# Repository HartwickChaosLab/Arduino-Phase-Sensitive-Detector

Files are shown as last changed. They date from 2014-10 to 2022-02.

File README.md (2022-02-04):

Arduino-Phase-Sensitive-Detector
================================

Arduino and Processing Code GPLv3
Talk CC-BY-SA 4.0

To use this software:
  Download: PSDArduino.ino from the PSDArduino folder and load onto your Arduino
  Download: PSDDrawProcessing.pde from the PSDDrawProcessing folder onto your computer
  
With your arduino running PSDArduino and connected to your computer, run PSDDrawProcessing.pde in the Processing environment

To use the PSD follow PSD_schematic_phase_schem.pdf found in the PSD-Talk folder.

To test the PSD with a phase-shifting circuit follow PhaseShift.pdf in the PSD-Talk folder. The input of the ciruit is attached to the Arduino port supplying the reference signal, the output goes to the Arduino input grabbing the signal. The resistors in the inverting branch should be roughly equal to provide 1V/V gain. I used 10k resistors. The pot in the non-inverting branch was 10k and the capacitor was chosen to create a 90 degree phase shift at the reference frequency, which occurs at 1/(2*pi*R*C). The reference frequency is determined by the Arduino code by fr=(TCNT2 rate)/(OCR2A * wavetable length)

20220202 Forrest Erickson
For the Processing sketch I have modified to show all four traces 

I have added sqaure wave output on pins 7 and 8.
I have moved the sine and cosine table into PROGMEM so 
Sketch uses 4832 bytes (14%) of program storage space. Maximum is 32256 bytes.
Global variables use 715 bytes (34%) of dynamic memory, leaving 1333 bytes for local variables. Maximum is 2048 bytes.

I have stopped the overlfow on the mixer mathematics and scaled the output to -2.5 to 2.5 around Vcc/2.

Here is the Arduino serial plotter output when I input the sqaure wave into the analog input (which I moved to A2 for my hardware) for both the pins 8 and 7 (in phage and 90 degree shift)

**ScreenCaptureIQMPV2.0.0.gif**
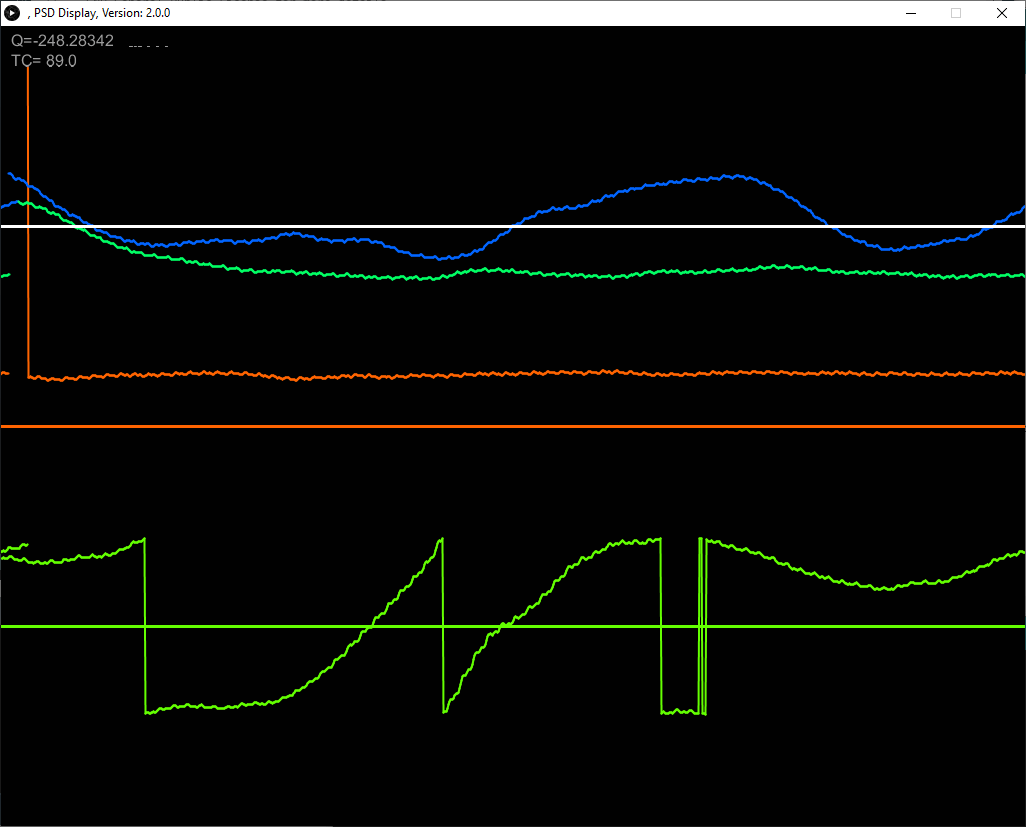
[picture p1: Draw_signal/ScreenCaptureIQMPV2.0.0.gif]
  

**SerialPlotPin8I**  
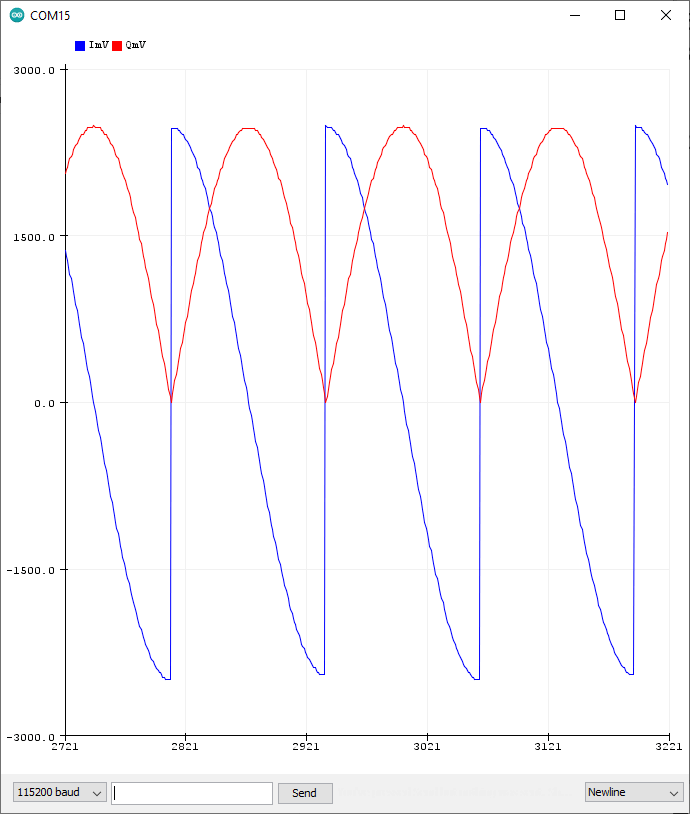
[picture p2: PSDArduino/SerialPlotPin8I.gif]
  
 
**SerialPlotPin7Q**  
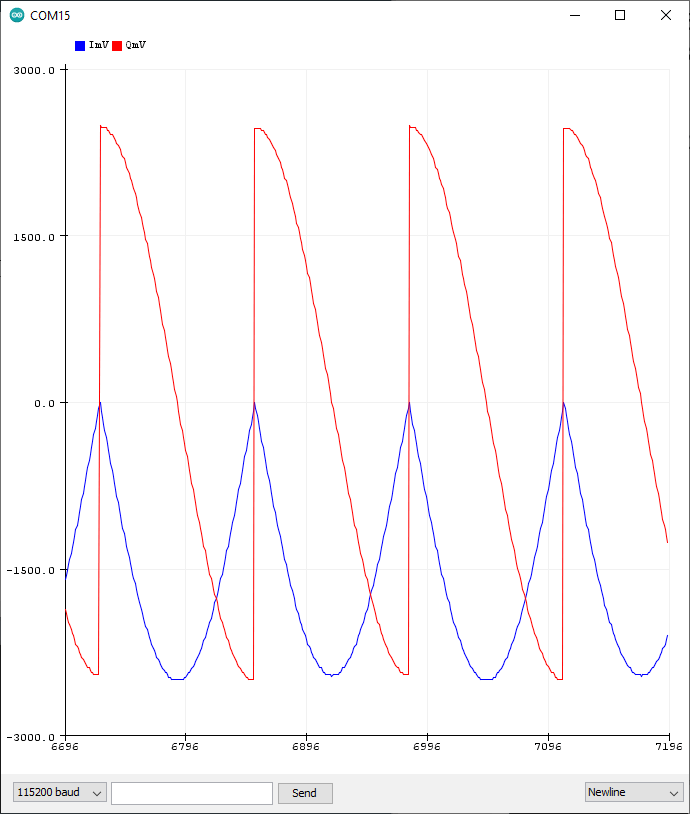
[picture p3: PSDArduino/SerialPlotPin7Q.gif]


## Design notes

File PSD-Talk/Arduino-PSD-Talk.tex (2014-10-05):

% !TEX TS-program = pdflatex
% !TEX encoding = UTF-8 Unicode

% This file is a template using the "beamer" package to create slides for a talk or presentation
% - Talk at a conference/colloquium.
% - Talk length is about 20min.
% - Style is ornate.

% MODIFIED by Jonathan Kew, 2008-07-06
% The header comments and encoding in this file were modified for inclusion with TeXworks.
% The content is otherwise unchanged from the original distributed with the beamer package.

\documentclass{beamer}
\usepackage{hyperref}

%This file is released under (CC BY-SA 4.0) license. See the following website for details http://creativecommons.org/licenses/by-sa/4.0/legalcode

\mode<presentation>
{
  \usetheme{Warsaw}
  % or ...

  %\setbeamercovered{transparent}
  % or whatever (possibly just delete it)
}

\usepackage[english]{babel}
% or whatever

\usepackage[utf8]{inputenc}
% or whatever
\usepackage[graphics]{}
\usepackage[amsmath]{}
\usepackage{times}
\usepackage[T1]{fontenc}
% Or whatever. Note that the encoding and the font should match. If T1
% does not look nice, try deleting the line with the fontenc.

\title[PSD with Arduino CC-BY-SA.4.0] % (optional, use only with long paper titles)
{The trials and tribulations of building a phase-sensitive detector with an Arduino microcontroller}

\author[K.\ D.\ Schultz] % (optional, use only with lots of authors)
{K.~D.~Schultz}
% - Give the names in the same order as the appear in the paper.
% - Use the \inst{?} command only if the authors have different
%   affiliation.

\institute[Hartwick College] % (optional, but mostly needed)
{
 
  Department of Physics\\
  Hartwick College
}
% - Use the \inst command only if there are several affiliations.
% - Keep it simple, no one is interested in your street address.

\date[MAS-APS] % (optional, should be abbreviation of conference name)
{MAS-APS, 2014}
% - Either use conference name or its abbreviation.
% - Not really informative to the audience, more for people (including
%   yourself) who are reading the slides online

% This is only inserted into the PDF information catalog. Can be left
% out. 

% If you have a file called "university-logo-filename.xxx", where xxx
% is a graphic format that can be processed by latex or pdflatex,
% resp., then you can add a logo as follows:

 \pgfdeclareimage[height=0.5cm]{university-logo}{HartwickLogo}
 \logo{\pgfuseimage{university-logo}}

% Delete this, if you do not want the table of contents to pop up at
% the beginning of each subsection:
%\AtBeginSubsection[]
%{
%  \begin{frame}<beamer>{Outline}
%    \tableofcontents[currentsection,currentsubsection]
%  \end{frame}
%}

% If you wish to uncover everything in a step-wise fashion, uncomment
% the following command: 

%\beamerdefaultoverlayspecification{<+->}

\begin{document}

\begin{frame}
  \titlepage
\end{frame}

%\begin{frame}{Outline}
%  \tableofcontents
%  % You might wish to add the option [pausesections]
%\end{frame}

% Structuring a talk is a difficult task and the following structure
% may not be suitable. Here are some rules that apply for this
% solution: 

% - Exactly two or three sections (other than the summary).
% - At *most* three subsections per section.
% - Talk about 30s to 2min per frame. So there should be between about
%   15 and 30 frames, all told.

% - A conference audience is likely to know very little of what you
%   are going to talk about. So *simplify*!
% - In a 20min talk, getting the main ideas across is hard
%   enough. Leave out details, even if it means being less precise than
%   you think necessary.
% - If you omit details that are vital to the proof/implementation,
%   just say so once. Everybody will be happy with that.

\section {Introduction}

\subsection{Original Goals}

\begin{frame}
\frametitle{Original Goals}

\begin{itemize}%[<+-|alert@+>]
\item {Use Arduino as a tool for teaching about phase-sensitive detection.}
\item{To do so with only the Arduino, a computer for display purposes, and passive external components (resistors and capacitors)}

\end{itemize}
\end{frame}

\subsection{Motivation}
\begin{frame}
\frametitle{Why PSD?}
\begin{itemize}%[<+-| alert@+>]
\item{Phase Sensitive Detection (PSD) is the basis of many techniques in physics and engineering}
\begin{itemize}
\item{Homodyne detection}
\item{Interferometry}
\item{Lock-in amplifiers}

\end{itemize}

\item {Black boxes are useful for application work, but not so much for pedagogical purposes}
\item {Software PSD allows students to peek into the black box.}

\end{itemize}

\end{frame}
\begin{frame}
\frametitle{Why Arduino?}
\begin{columns}[t]
\column[c]{0.6\textwidth}
\begin{itemize}
\item{Cheap}
\item {Popular}
\begin{itemize}
\item {Lots of support}
\end{itemize}
\item {Simple programming environment}
\begin{itemize}
\item {Perhaps too simple, IDE has very poor debugging tools.}
\end{itemize}
\item{Works well with Processing, which is a free and powerful language for visualization}
\item{Both Arduino and Processing are platform agnostic: Windows, Linux, OS X, Raspberry Pi...}
\end{itemize}
\column[c]{0.4\textwidth}
\begin{figure}
\hspace*{-.75cm}\\
\tiny {Arduino picture from Sparkfun CC-BY-2.0}
\end{figure}
\end{columns}
\end{frame}

\subsection{Background Material}
\begin{frame}
\frametitle{PSD Basics}

\begin{columns}[t]
	\column[c]{4.5cm}
	    
	\column[c]{6.6cm}
\small	
	\begin{block}{Mathematics of PSD}
	
	\begin{align*}
	V_{mix}&=V_s V_r \left [ ( \cos\left(\omega_s-\omega_r\right)t-(\phi_s-\phi_r)\right]\\
	V_o&=A \frac{V_s V_r}{2} \left[ \cos(\phi_s-\phi_r)\right]
	\end{align*}
	
	\end{block}

\begin{block}{Restrictions}
\begin{itemize}
\item $\omega_r=\omega_s$
\item\alert{ $V_s$ and $V_r$ have no DC offset}
\end{itemize}
\end{block}

\end{columns}
\end{frame}

\section{Is This Even Possible?}

%\begin{frame}
%\frametitle{What do we need? Can we do it?}
%\begin{columns}
%\column[T]{.5\textwidth}
%\begin{block}{Needed features}
%\begin{enumerate}
%
%\item {Generate reference signal.}
%\item {Adjustable phase to maximize signal.}
%\item {Get signal into Arduino}
%\item {Mix signal and reference and filter the results}
%\item {Display results}
%\end{enumerate}
%\end{block}
%\pause
%\column[T]{.5\textwidth}
%\begin{block}{Issues}
%\begin{enumerate}%[<+->]
%\item{Arduino has no analog out}
%\item{Shifting phase is difficult to do internally}
%\item{Positive voltages only}
%\item{Limited variable memory on Arduino}
%\item{Need to use serial over USB to Processing}
%\end{enumerate}
%\end{block}
%\end{columns}
%\end{frame}

\begin{frame}
\frametitle{Flowchart}

\end{frame}

\subsection{Making it Work}
\begin{frame}
\frametitle{Phase Manipulation}
\begin{columns}[t]
\column[c]{0.3\textwidth}


\column[c]{0.7\textwidth}

\begin{itemize}
\item {Need to be able to shift phase to maximize signal}
\item {All-pass phase shifters work, but require a bit more hardware external to Ardunio}
\item {Software solutions difficult to implement}
\item {Use two phase detection.}
	\begin{itemize}
	\item $V_I=V_s\times \cos(\theta), V_Q=V_s\times\sin(\theta)$
	\item $R=\sqrt{V_I^2+V_Q^2}$
	\item $\phi=\tan^{-1}(V_Q/V_I)$
	\end{itemize}
\end{itemize}

\end{columns}
\end{frame}

\begin{frame}
\frametitle{Creating a Reference Signal}
\begin{columns}[t]
	\column[c]{6cm}
	\begin{figure}
	    \\
	    \tiny{ Picture adapted from J. Thompson, MAKE vol. 35}
	    \end{figure}
	    
	\column[c]{5cm}

	\begin{block}{Timers and Interrupts Part I}
	\begin{itemize}
	\item {The ratio of PWM on to off determines an average ``DC'' signal}
	\item{When register TCNT1 reaches OCR1A PWM goes low}
	\item {When TCNT1 overflows PWM goes high again}
	\end{itemize}
	
	\end{block}
\end{columns}
\end{frame}

\begin{frame}
\frametitle{Creating a Reference Signal}
\begin{columns}[T]
	\column[T]{.4\textwidth}
	\vspace{.5cm}
	   \begin{figure}
	    \\
	    \tiny {Picture adapted from J. Thompson, MAKE vol. 35}
	    \end{figure}
	    \vspace{.3cm}
	    \begin{block}
	    $f_{ref}=\frac{\text{TCNT2 rate}}{\text{OCR2A value}\times\text{wavetable length}}$
	    \end{block}
	\column[T]{.5\textwidth}

	\begin{block}{Timers and Interrupts Part II}
	\begin{itemize}
	\item {Need fast timer2 and regular timer1, which outputs PWM}
	\item{When timer2 reaches OCR2A:}
	\begin{itemize}
        \item {Update OCR1A from wavetable}
        \item{ read signal at AnalogIn}
	\end{itemize}
	\item{When timer1 counts up to OCR1A, PWM goes low}
	\item {When timer1 overflows PWM goes high again}
	
	\end{itemize}
	
	\end{block}
\end{columns}
\end{frame}

\begin{frame}
\frametitle{Signal Input}
\begin{center}
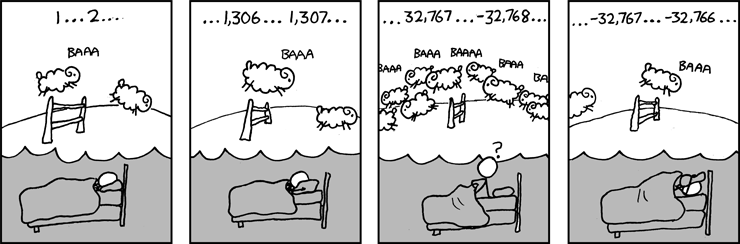
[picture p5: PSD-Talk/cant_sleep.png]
\hspace*{-.45cm}
\end{center}
\end{frame}
\begin{frame}
\frametitle{Signal Input}
\begin{itemize}
	\item {Arduino can only have positive voltages at its inputs or outputs}
		\begin{itemize}
			\item {Integer overflow when mixing}
			\item {Necessary DC offsets makes phase indefinite}
		\end{itemize}
	\item {Need to run ADC as fast as we can so as to to interfere with reference generation.}

		\begin{itemize}
			\item{Setting pre-scalars and registers can get sampling rates of 50k samples/sec. Not bad for  a 30 board!}
			\item{ADC has 10 bit resolution with adjustable $V_{ref}$, so resolution on the order of a millivolt is possible}
		\end{itemize}
\end{itemize}

\end{frame}

\begin{frame}
\frametitle{Display}
\begin{columns}
\column{.5\textwidth}
\begin{figure}
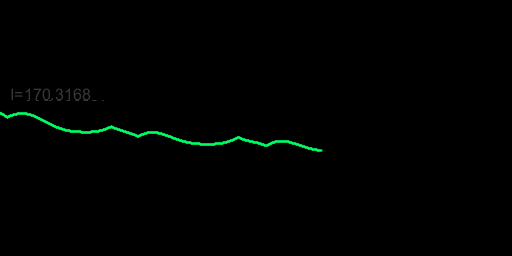
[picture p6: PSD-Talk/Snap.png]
\\
In-phase channel as phase is changed
\end{figure}
\column{.5\textwidth}

\end{columns}
\end{frame}

\section{Conclusions}
\begin{frame}
\begin{columns}
\column[T]{.5\textwidth}
\begin{block}{What we accomplished}
\begin{itemize}
\item {Built and tested a working two-channel phase-sensitive detector}
\item {Learned techniques that can be used for other micro-processor based instruments}
\item {Published on github under GPL v3 license}
\end{itemize}
\end{block}

\column[T]{.5\textwidth}
\begin{block}{Still to do}
\begin{itemize}
\item {Characterize detector (noise, internal phase shift, etc...)}
\item {Clean up display}
\item {Explore other memory options on Arduino}
\item {Use in an application}
\end{itemize}
\end{block}
\end{columns}
\end{frame}
% All of the following is optional and typically not needed. 
\appendix
\section<presentation>*{\appendixname}
\subsection<presentation>*{For Further Reading}

\begin{frame}[allowframebreaks]
  \frametitle<presentation>{For Further Reading}
    
  \begin{thebibliography}{10}
    
%  \beamertemplatebookbibitems
%  % Start with overview books.
%
%  \bibitem{Author1990}
%    A.~Author.
%    \newblock {\em Handbook of Everything}.
%    \newblock Some Press, 1990.

  \beamertemplateinternetbibitems
  % Followed by interesting articles. Keep the list short. 
\small{
  \bibitem{github2014}
    The programs!
    \newblock \url{https://github.com/HartwickChaosLab/Arduino-Phase-Sensitive-Detector}
   
   \bibitem{arduino}
   Arduino
   \newblock \url{http://www.arduino.cc}
   
   \bibitem{Processing}
   Processing
   \newblock \url{http://processing.org}
   
   \bibitem{measuring stuff}
   Moding the Arduino ADC
   \newblock \url{https://sites.google.com/site/measuringstuff/the-arduino}
  
   \beamertemplatearticlebibnitems
 
   \bibitem{Make35}
     J.~Thompson
     \newblock ``Advanced Arduino Sound Synthesis"
     \newblock Make Vol. 35 
   }
  \end{thebibliography}
\end{frame}

\end{document}

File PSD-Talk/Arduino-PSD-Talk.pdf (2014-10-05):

Introduction
Is This Even Possible?
Conclusions

# The trials and tribulations of building a phase-sensitive detector with an Arduino microcontroller

# K. D. Schultz

## Department of Physics Hartwick College

# MAS-APS, 2014

K. D. Schultz | PSD with Arduino CC-BY-SA.4.0

Conclusions

Original Goals
Motivation
Background Material

# Original Goals

# Use Arduino as a tool for teaching about phase-sensitive

detection.

# To do so with only the Arduino, a computer for display purposes, and passive external components (resistors and capacitors)

Conclusions

Original Goals
Motivation
Background Material

# Why PSD?

# Phase Sensitive Detection (PSD) is the basis of many techniques in physics and engineering

## Homodyne detection Interferometry Lock-in amplifiers

# Black boxes are useful for application work, but not so much for pedagogical purposes

Software PSD allows students to peek into the black box.

Conclusions

Original Goals
Motivation
Background Material

# Why Arduino?

# Cheap Popular

## Lots of support

# Simple programming environment

## Perhaps too simple, IDE has

very poor debugging tools. Works well with Processing,

# which is a free and powerful language for visualization

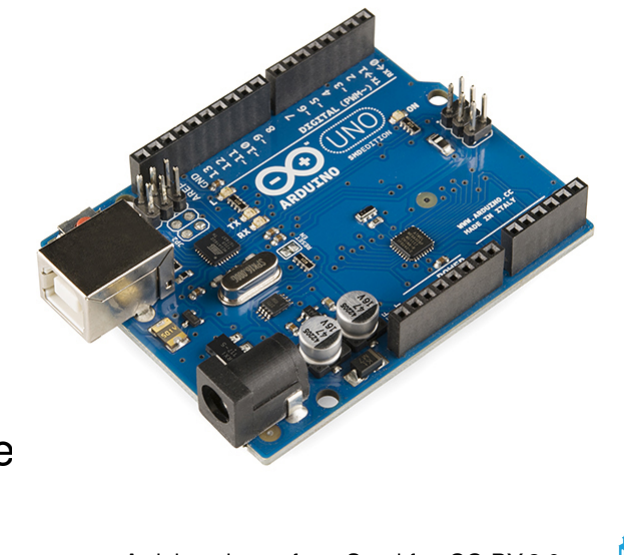
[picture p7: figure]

# Both Arduino and Processing are

platform agnostic: Windows,

Linux, OS X, Raspberry Pi... | Arduino picture from Sparkfun CC-BY-2.0

Conclusions

Original Goals
Motivation
Background Material

# PSD Basics

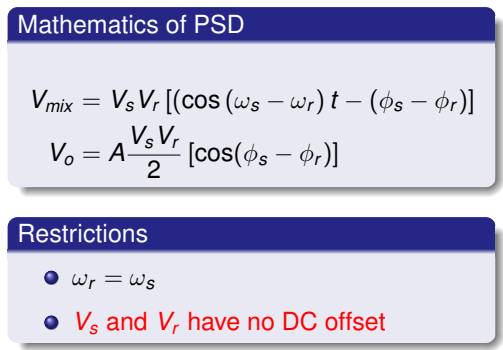
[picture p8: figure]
Mathematics of PSD; Vmix = VsVr; [(cos (ωs − ωr)t − (φs − φr)]; VsVr; [cos(φs − φr)]; Restrictions; Vs and Vr have no DC offset

# V LPF mix

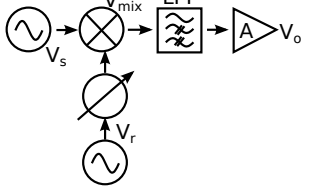
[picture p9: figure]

Conclusions

Making it Work

# Flowchart

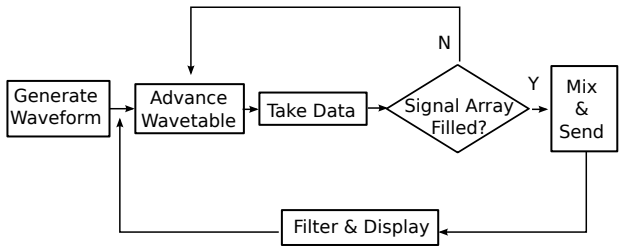
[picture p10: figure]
Advance Wavetable; Mix & Send; Generate; Waveform; Take Data; Signal Array; Filled?; Filter & Display

Conclusions

# Phase Manipulation

# Need to be able to shift phase to

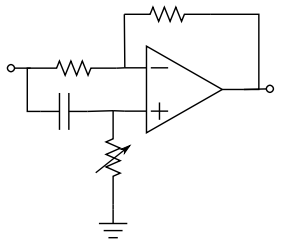
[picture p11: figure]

# maximize signal

# All-pass phase shifters work, but require a bit more hardware external to Ardunio

# Software solutions difficult to implement

Use two phase detection.

## VI = Vs × cos(θ), VQ = Vs × sin(θ)

R =

q
V

2
I + V

2
Q

## φ = tan⁻¹

# (VQ/VI)

Conclusions

# Creating a Reference Signal

### PWM Output

0

255

### TCNTn

### TCNTn=OCRnA

Picture adapted from J. Thompson, MAKE vol. 35

# Timers and Interrupts Part I

# The ratio of PWM on to off determines an average “DC” signal

# When register TCNT1

# reaches OCR1A PWM

# goes low

# When TCNT1 overflows PWM goes high again

Conclusions

# Creating a Reference Signal

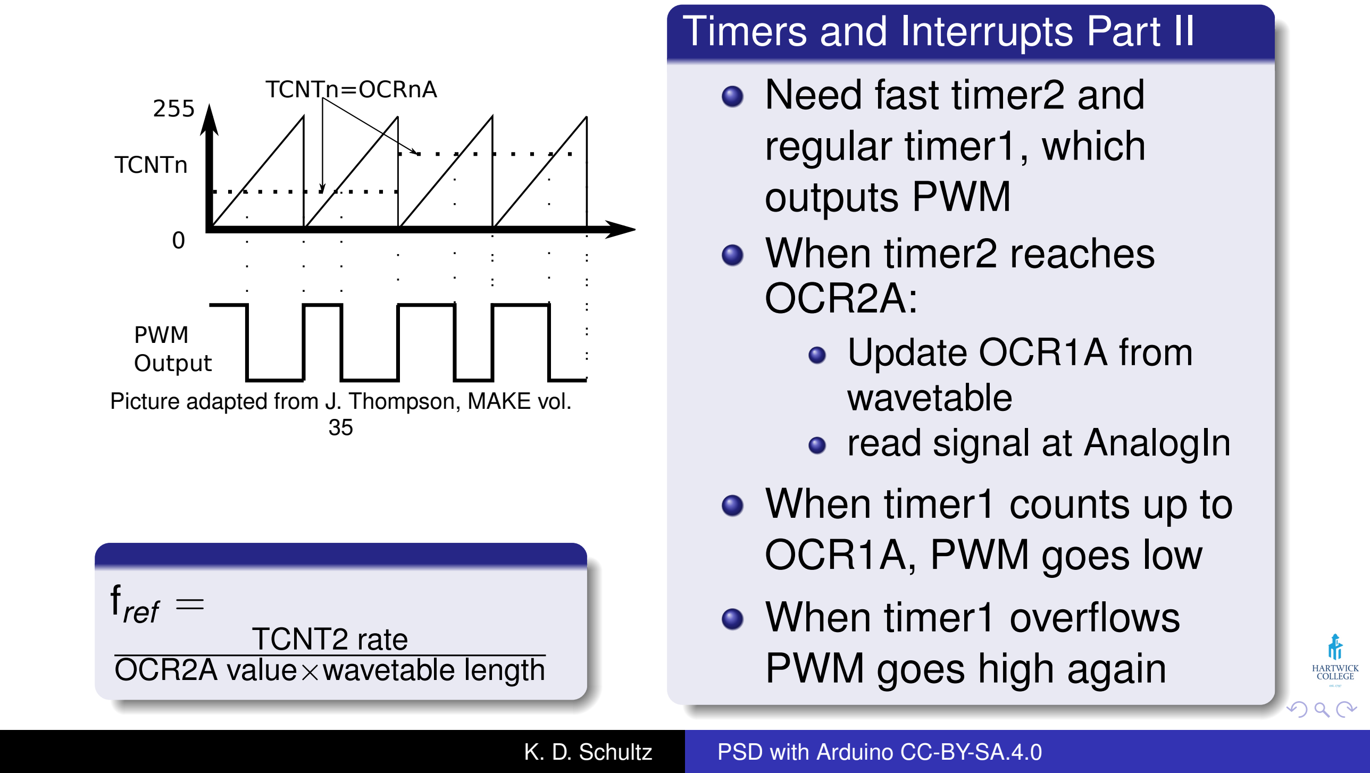
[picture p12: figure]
PWM Output; TCNTn; TCNTn=OCRnA; fref =; TCNT2 rate OCR2A value×wavetable length; Timers and Interrupts Part II; Need fast timer2 and regular timer1, which outputs PWM When timer2 reaches OCR2A:; Update OCR1A from wavetable read signal at AnalogIn; When timer1 counts up to OCR1A, PWM goes low; When timer1 overflows PWM goes high again

Picture adapted from J. Thompson, MAKE vol.

Conclusions

# Signal Input

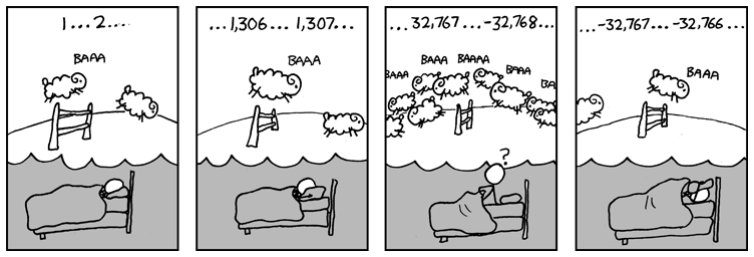
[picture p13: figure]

Conclusions

# Signal Input

# Arduino can only have positive voltages at its inputs or outputs

## Integer overflow when mixing Necessary DC offsets makes phase indefinite

# Need to run ADC as fast as we can so as to to interfere

with reference generation.

## Setting pre-scalars and registers can get sampling rates of 50k samples/sec. Not bad for a 30 board! ADC has 10 bit resolution with adjustable Vref , so resolution on the order of a millivolt is possible

Conclusions

# Display

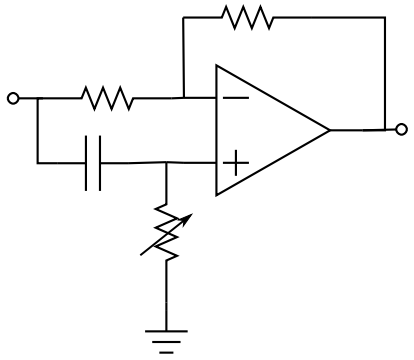
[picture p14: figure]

# In-phase channel as phase is changed

Conclusions

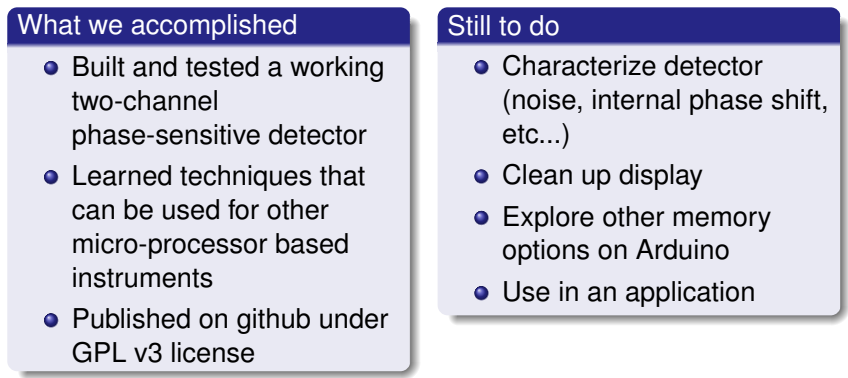
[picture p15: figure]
What we accomplished; Built and tested a working two-channel phase-sensitive detector; Learned techniques that can be used for other micro-processor based instruments; Published on github under GPL v3 license; Still to do; Characterize detector (noise, internal phase shift, etc...); Clean up display; Explore other memory options on Arduino; Use in an application

Appendix | For Further Reading

# For Further Reading I

## The programs!

## https://github.com/HartwickChaosLab/

Arduino-Phase-Sensitive-Detector (https://github.com/HartwickChaosLab/Arduino-Phase-Sensitive-Detector)

## Arduino

## http://www.arduino.cc

## Processing

## http://processing.org

# Moding the Arduino ADC

## https://sites.google.com/site/measuringstuff/

## the-arduino (https://sites.google.com/site/measuringstuff/the-arduino)

## J. Thompson “Advanced Arduino Sound Synthesis" Make Vol. 35

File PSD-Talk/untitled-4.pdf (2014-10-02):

Introduction
Is This Even Possible?
Conclusions

# The trials and tribulations of building a phase-sensitive detector with an Arduino microcontroller

# K. D. Schultz

## Department of Physics Hartwick College

# MAS-APS, 2014

K. D. Schultz | PSD with Arduino

# Outline

1 | Introduction Original Goals Motivation Background Material
2 | Is This Even Possible? Initial Proposal Making it Work
3 | Conclusions

Original Goals
Motivation
Background Material

# Original Goals

# Use Arduino as a tool for teaching about phase-sensitive

detection, like.....

# Original Goals

# Use Arduino as a tool for teaching about phase-sensitive

detection, like.....

# To do so with only the Arduino, a computer for display purposes, and passive external components (resistors and capacitors)

# Original Goals

# Use Arduino as a tool for teaching about phase-sensitive

detection, like.....

# To do so with only the Arduino, a computer for display purposes, and passive external components (resistors and capacitors)

# Original Goals

# Use Arduino as a tool for teaching about phase-sensitive

detection, like.....

# To do so with only the Arduino, a computer for display purposes, and passive external components (resistors and capacitors)

# Can be done, but different lessons are learned

# Why PSD?

# Phase Sensitive Detection (PSD) is the basis of many techniques in physics and engineering

# Why PSD?

# Phase Sensitive Detection (PSD) is the basis of many techniques in physics and engineering

## Homodyne detection

# Why PSD?

# Phase Sensitive Detection (PSD) is the basis of many techniques in physics and engineering

## Homodyne detection Interferometry

# Why PSD?

# Phase Sensitive Detection (PSD) is the basis of many techniques in physics and engineering

## Homodyne detection Interferometry Lock-in amplifiers

# Why PSD?

# Phase Sensitive Detection (PSD) is the basis of many techniques in physics and engineering

## Homodyne detection Interferometry Lock-in amplifiers

# Black boxes are useful for application work, but not so much for pedagogical purposes

# Why PSD?

# Phase Sensitive Detection (PSD) is the basis of many techniques in physics and engineering

## Homodyne detection Interferometry Lock-in amplifiers

# Black boxes are useful for application work, but not so much for pedagogical purposes

Software PSD allows students to peek into the black box.

# Why Arduino?

# Cheap

# Why Arduino?

# Cheap Popular

# Why Arduino?

# Cheap Popular

## Lots of support

# Why Arduino?

# Cheap Popular

## Lots of support

# Simple programming environment

# Why Arduino?

# Cheap Popular

## Lots of support

# Simple programming environment

Perhaps too simple, IDE has very poor debugging tools.

# Why Arduino?

# Cheap Popular

## Lots of support

# Simple programming environment

Perhaps too simple, IDE has very poor debugging tools.

## Really no debugging tools, except for serial out

# PSD Basics

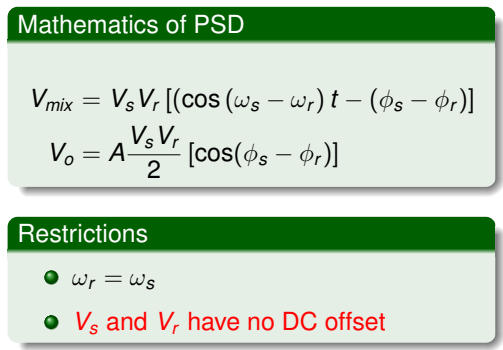
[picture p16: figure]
Mathematics of PSD; Vmix = VsVr; [(cos (ωs − ωr)t − (φs − φr)]; VsVr; [cos(φs − φr)]; Restrictions; Vs and Vr have no DC offset

# V LPF mix

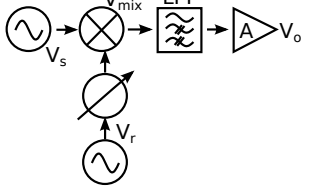
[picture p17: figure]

# Let’s Make a PSD

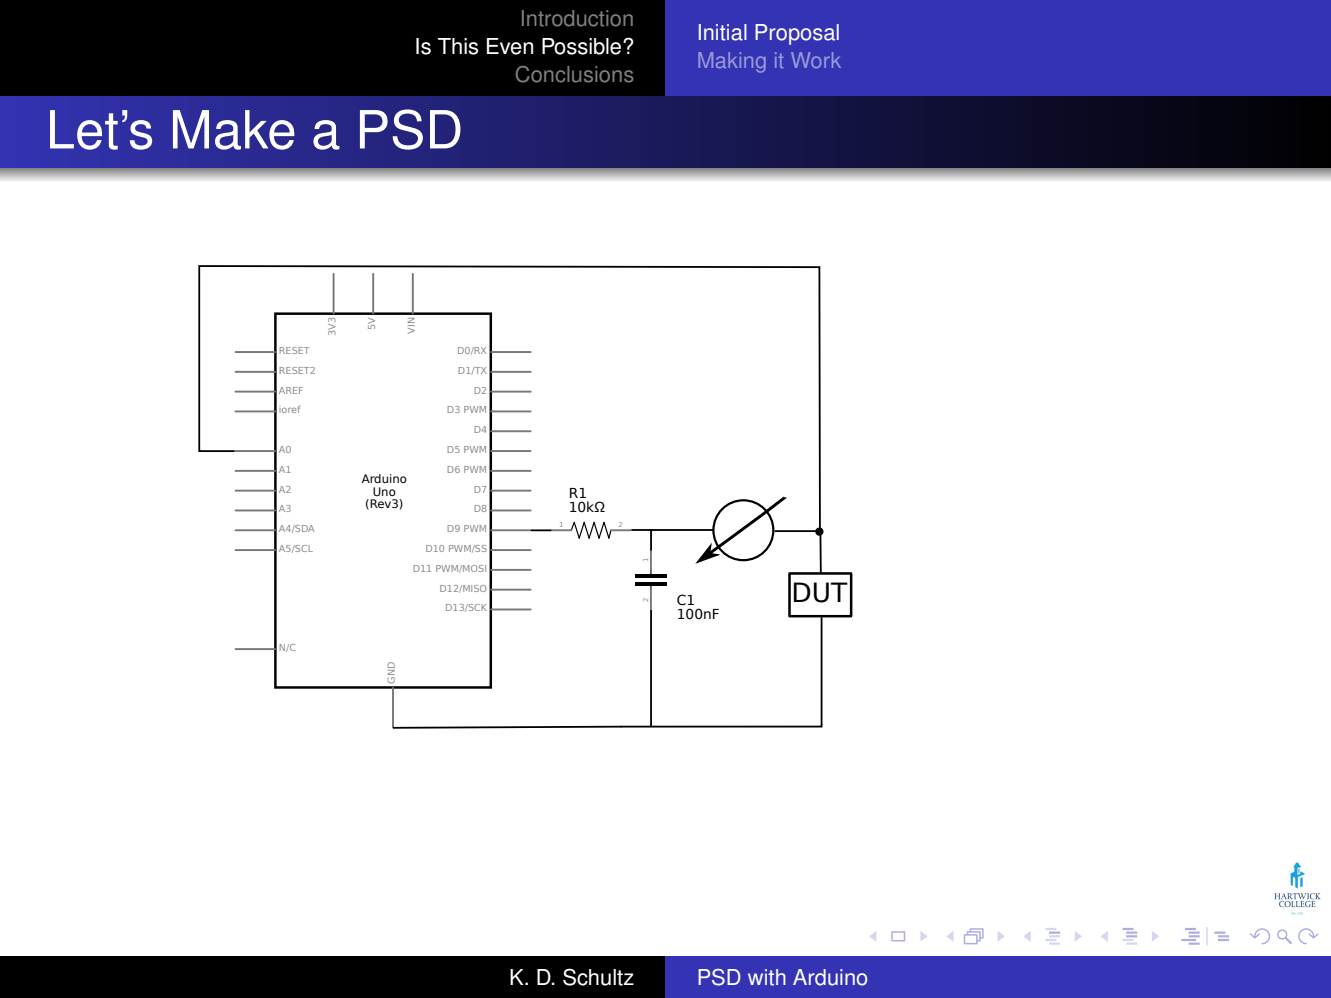
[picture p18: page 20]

Initial Proposal
Making it Work

# How did it go?

Initial Proposal
Making it Work

# Pseudo Code

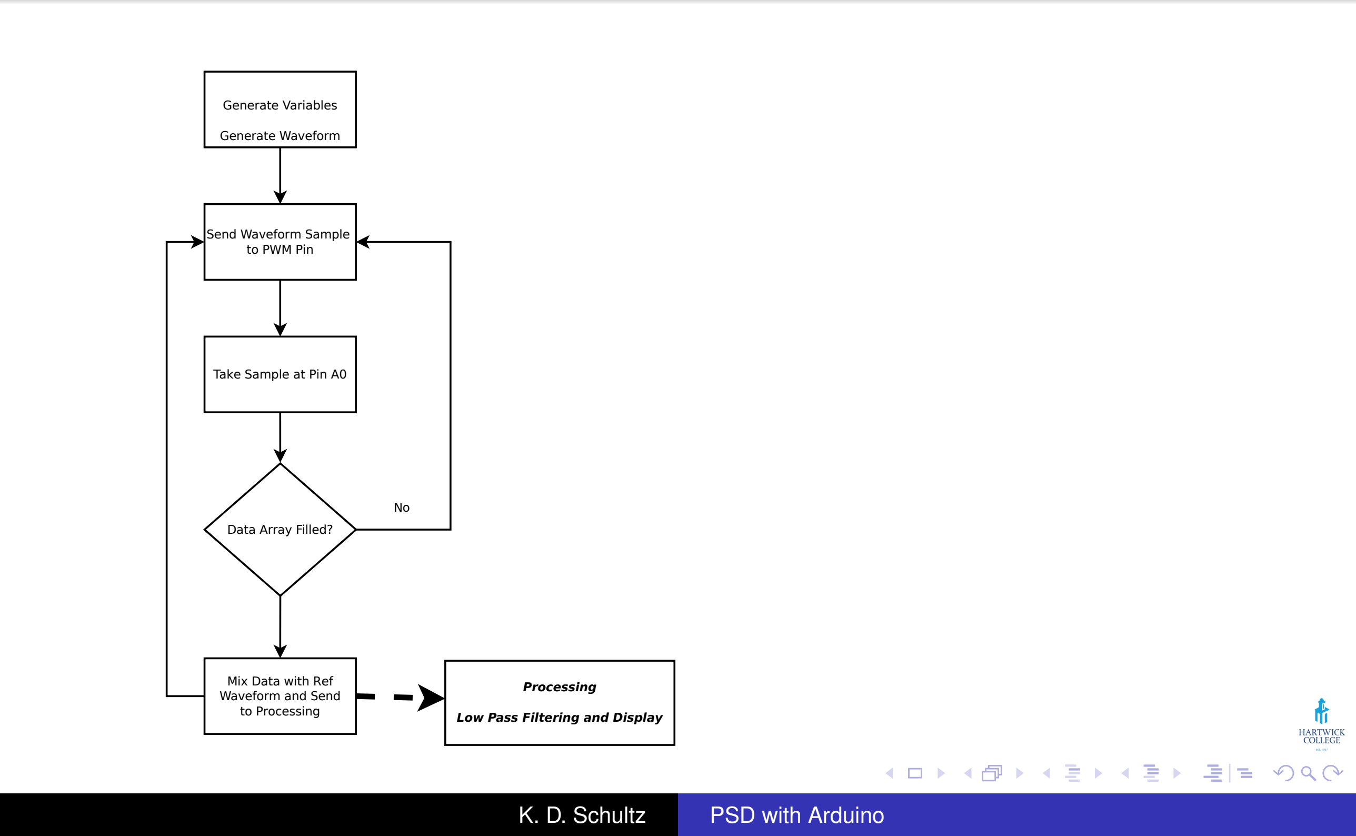
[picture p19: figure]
Generate Variables; Generate Waveform; Send Waveform Sample to PWM Pin; Take Sample at Pin A0; Data Array Filled?; Mix Data with Ref Waveform and Send to Processing; Processing; Low Pass Filtering and Display

Initial Proposal
Making it Work

# Creating a Reference Signal

### PWM Output

0

255

### TCNTn

### TCNTn=OCRnA

# Timers and Interrupts Part I

# The ratio of PWM on to off determines an average “DC” signal

# When register TCNT1

# reaches OCR1A PWM

# goes low

# When TCNTn overflows PWM goes high again

Initial Proposal
Making it Work

# Creating a Reference Signal

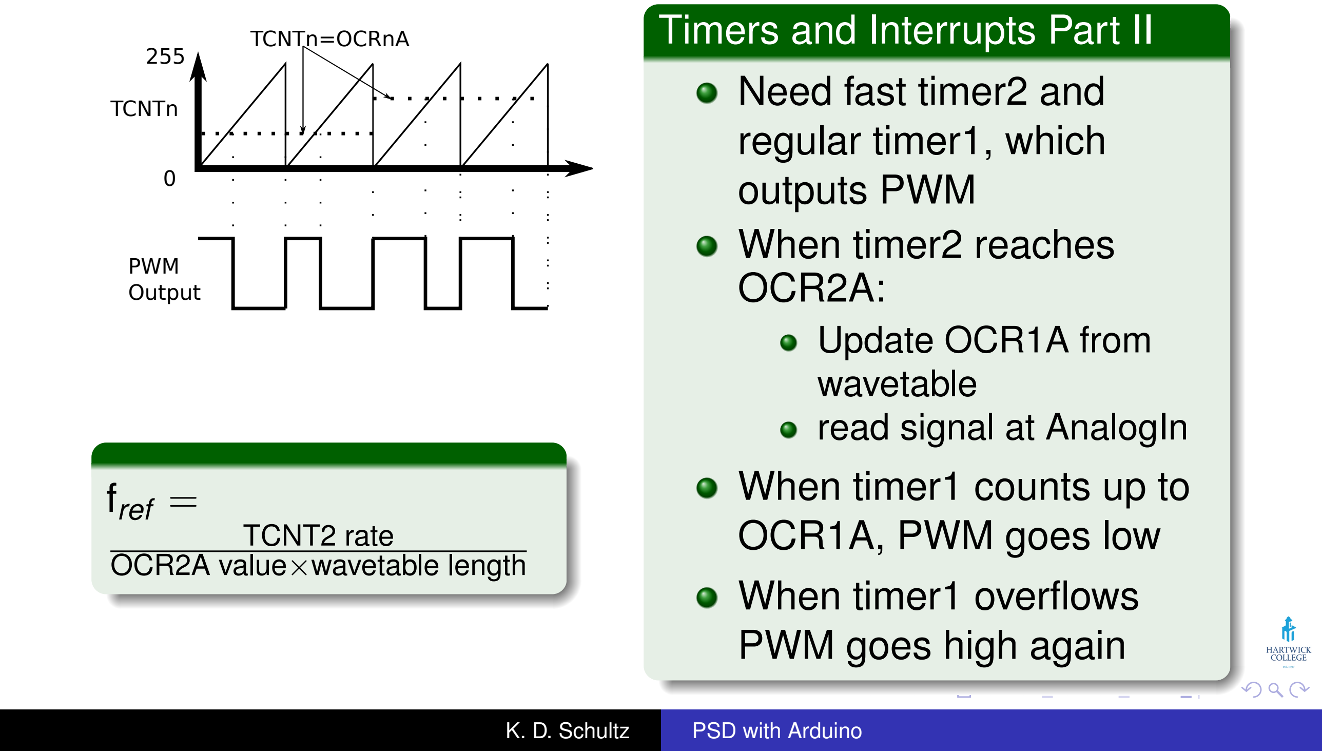
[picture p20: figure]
PWM Output; TCNTn; TCNTn=OCRnA; fref =; TCNT2 rate OCR2A value×wavetable length; Timers and Interrupts Part II; Need fast timer2 and regular timer1, which outputs PWM When timer2 reaches OCR2A:; Update OCR1A from wavetable read signal at AnalogIn; When timer1 counts up to OCR1A, PWM goes low; When timer1 overflows PWM goes high again

Initial Proposal
Making it Work

# Signal Input

Initial Proposal
Making it Work

# Phase Manipulation

Initial Proposal
Making it Work

# Display

Appendix | For Further Reading

# For Further Reading I

A. Author.
Handbook of Everything.
Some Press, 1990.
S. Someone.
On this and that.
Journal of This and That, 2(1):50–100, 2000.

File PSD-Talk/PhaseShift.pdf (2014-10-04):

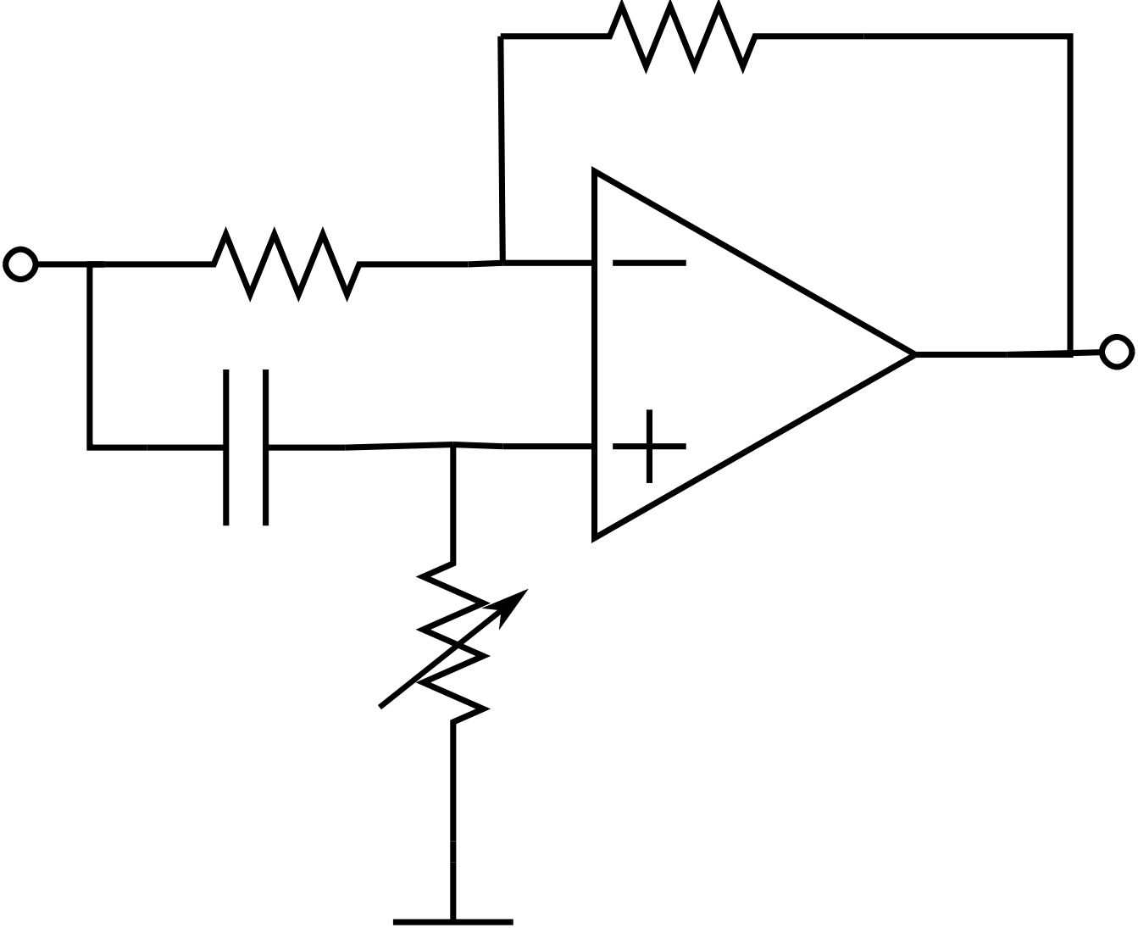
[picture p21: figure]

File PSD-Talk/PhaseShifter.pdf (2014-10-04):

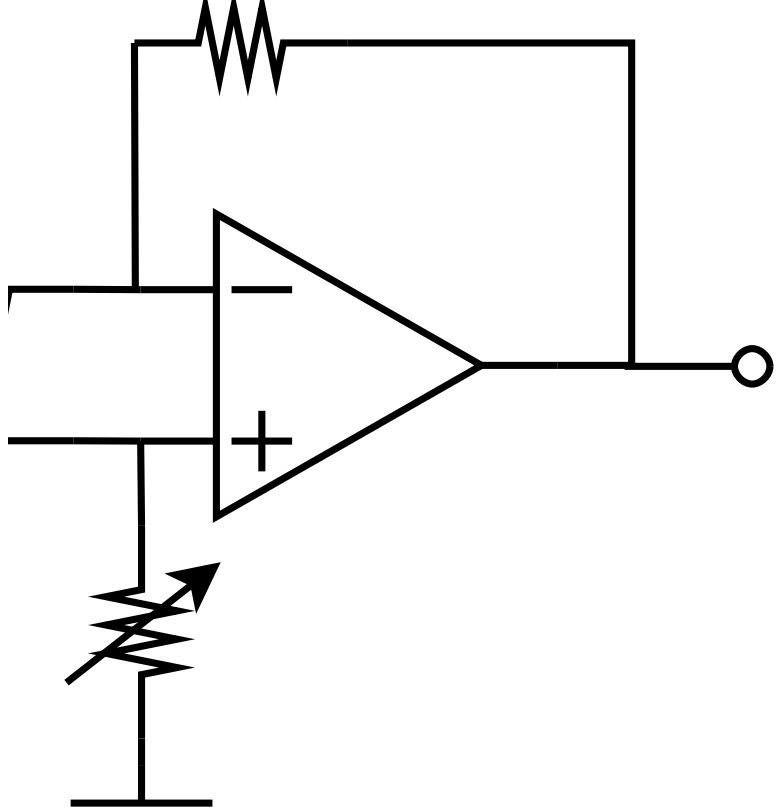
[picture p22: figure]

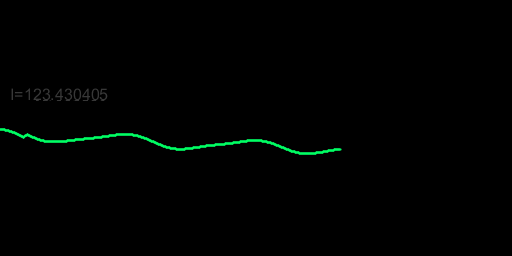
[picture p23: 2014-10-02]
PSD-Talk/ISnap.tif

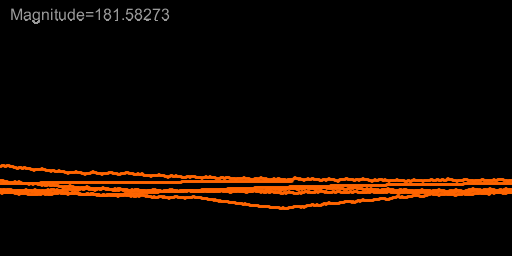
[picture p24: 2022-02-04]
PSDDrawProcessing/Snap.png

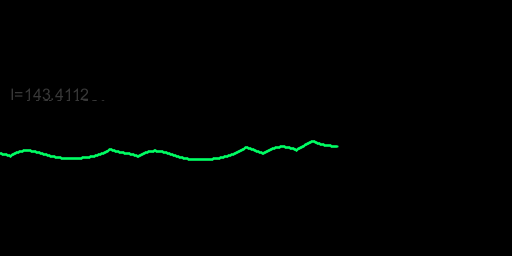
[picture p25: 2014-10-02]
PSDDrawProcessing/screen-1042.tif

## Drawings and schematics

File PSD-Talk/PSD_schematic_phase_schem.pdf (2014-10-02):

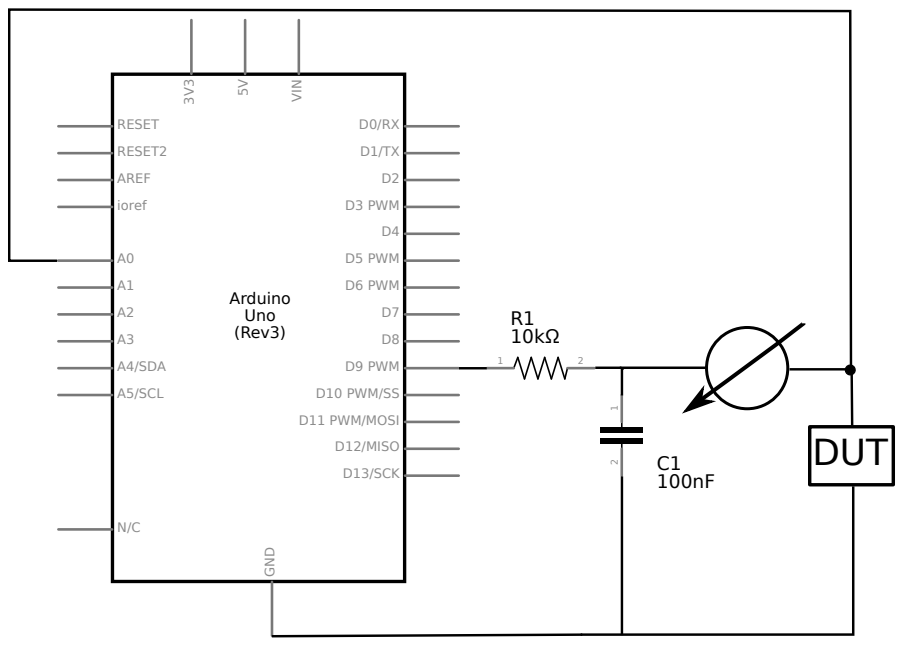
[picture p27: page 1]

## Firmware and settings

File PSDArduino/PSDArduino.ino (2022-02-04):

/* {PSDARduino
    Copyright (C) 2014  Kevin D. Schultz

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
    You should have received a copy of the GNU General Public License
    along with this program.  If not, see <http://www.gnu.org/licenses/>.*/

/* This program is used to configure the Arduino as a function
  generator and as DAQ. This sketch can be used in just this capacity,
  but is intended to be the reference signal generator and the front
  end of a Phase-Sensitive-Detector with the aid of Processing program
  2Ch-PSD.pde

  The reference signal is generated by modifiying the PWM on pin 9
  of an Arduino.This signal is smoothed with an RC ckt on the pin 9.
  A NPN transistor is used afterwards to drive an LED. The signal
  from a LED acting as a photodiode is read in from pin 0.

  To make this all work quickly, although it is not strictly necessary
  We run the ADC in it's fastest mode see, https://sites.google.com/site/measuringstuff/the-arduino

  See Fritzing Sketch PSD_sketch.fzz

*/

//Modified by FLE 20220130
// Download from:
//Add sync pin 8 output to trigger Oscilliscope on oscillator output
//Change variable types for sin/cos function table.
// 20220131 /Move sine and cosine into PROGMEM
// 20220201 Clean up comments
// Mul by 7.8125 to make mV.
// Add a syncQ output on pin 7.

#include <avr/interrupt.h>

#define PI2 6.283185
const int TABLE_OFFSET = 128;

//const int inputOFFSET = 1024/2;       //Theoritical input mid point.
const int inputOFFSET = 2.39 * 1023 / 4.80; //Measured on Resistive devider input FLE 20220201

#define REC_LENGTH 256                //Input signal array length
#define LENGTH 256                    //Sine Cosine table array length

const int syncPin = 8;  //Inphase sync
const int syncQPin = 7;  //Qphase sync

//const int myINPUT = 0;
const int myINPUT = A2;    //OctoUNO J1Pin1 input wire White/Orange

//ToDo make the sine and cosine 10bit resolution. Remove offset from table.
//Sine and cosine table of length = LENGTH = 256. Sine and cosine offset by 128. Range is 0-256.
const static int16_t PROGMEM wave_I[] = {
  255, 254, 254, 254, 254, 254, 253, 253, 252, 251, 251, 250, 249, 248, 247, 246, 245, 244, 242, 241, 240, 238, 236, 235, 233, 231, 230, 228, 226, 224, 222, 219, 217, 215, 213, 210, 208, 206, 203, 201, 198, 195, 193, 190, 187, 185, 182, 179, 176, 173, 170, 167, 164, 161, 158, 155, 152, 149, 146, 143, 140, 137, 134, 131, 128, 124, 121, 118, 115, 112, 109, 106, 103, 100, 97, 94, 91, 88, 85, 82, 79, 76, 73, 70, 68, 65, 62, 60, 57, 54, 52, 49, 47, 45, 42, 40, 38, 36, 33, 31, 29, 27, 25, 24, 22, 20, 19, 17, 15, 14, 13, 11, 10, 9, 8, 7, 6, 5, 4, 4, 3, 2, 2, 1, 1, 1, 1, 1, 1, 1, 1, 1, 1, 1, 2, 2, 3, 4, 4, 5, 6, 7, 8, 9, 10, 11, 13, 14, 15, 17, 19, 20, 22, 24, 25, 27, 29, 31, 33, 36, 38, 40, 42, 45, 47, 49, 52, 54, 57, 60, 62, 65, 68, 70, 73, 76, 79, 82, 85, 88, 91, 94, 97, 100, 103, 106, 109, 112, 115, 118, 121, 124, 128, 131, 134, 137, 140, 143, 146, 149, 152, 155, 158, 161, 164, 167, 170, 173, 176, 179, 182, 185, 187, 190, 193, 195, 198, 201, 203, 206, 208, 210, 213, 215, 217, 219, 222, 224, 226, 228, 230, 231, 233, 235, 236, 238, 240, 241, 242, 244, 245, 246, 247, 248, 249, 250, 251, 251, 252, 253, 253, 254, 254, 254, 254, 254
};

const static int16_t PROGMEM wave_Q[] = {
  128, 131, 134, 137, 140, 143, 146, 149, 152, 155, 158, 161, 164, 167, 170, 173, 176, 179, 182, 185, 187, 190, 193, 195, 198, 201, 203, 206, 208, 210, 213, 215, 217, 219, 222, 224, 226, 228, 230, 231, 233, 235, 236, 238, 240, 241, 242, 244, 245, 246, 247, 248, 249, 250, 251, 251, 252, 253, 253, 254, 254, 254, 254, 254, 255, 254, 254, 254, 254, 254, 253, 253, 252, 251, 251, 250, 249, 248, 247, 246, 245, 244, 242, 241, 240, 238, 236, 235, 233, 231, 230, 228, 226, 224, 222, 219, 217, 215, 213, 210, 208, 206, 203, 201, 198, 195, 193, 190, 187, 185, 182, 179, 176, 173, 170, 167, 164, 161, 158, 155, 152, 149, 146, 143, 140, 137, 134, 131, 128, 124, 121, 118, 115, 112, 109, 106, 103, 100, 97, 94, 91, 88, 85, 82, 79, 76, 73, 70, 68, 65, 62, 60, 57, 54, 52, 49, 47, 45, 42, 40, 38, 36, 33, 31, 29, 27, 25, 24, 22, 20, 19, 17, 15, 14, 13, 11, 10, 9, 8, 7, 6, 5, 4, 4, 3, 2, 2, 1, 1, 1, 1, 1, 1, 1, 1, 1, 1, 1, 2, 2, 3, 4, 4, 5, 6, 7, 8, 9, 10, 11, 13, 14, 15, 17, 19, 20, 22, 24, 25, 27, 29, 31, 33, 36, 38, 40, 42, 45, 47, 49, 52, 54, 57, 60, 62, 65, 68, 70, 73, 76, 79, 82, 85, 88, 91, 94, 97, 100, 103, 106, 109, 112, 115, 118, 121, 124,
};

volatile byte index = 0; // Points to each table entry. declare as volatile so other functions can see it.

int signal[REC_LENGTH]; // Captures Signal Data into array

/* We are going to reconfigure ADC to be faster to go to regular speed
  change to #define FASTADC 0 */
#define FASTADC 1
// defines for setting and clearing register bits
#ifndef cbi
#define cbi(sfr, bit) (_SFR_BYTE(sfr) &= ~_BV(bit))
#endif
#ifndef sbi
#define sbi(sfr, bit) (_SFR_BYTE(sfr) |= _BV(bit))
#endif

void setup() {
  // put your setup code here, to run once:
  Serial.begin(115200); ////FLE Make Faster
  delay(100);
  Serial.println("ImV, QmV");       //Set scale for serial ploter
  pinMode(syncPin, OUTPUT);         //Setup a pin for sync signal output
  digitalWrite(syncPin, HIGH);
  pinMode(syncQPin, OUTPUT);         //Setup a pin for sync Q signal output
  digitalWrite(syncQPin, HIGH);

  

#if FASTADC
  // set prescale to 16
  sbi(ADCSRA, ADPS2) ;
  cbi(ADCSRA, ADPS1) ;
  cbi(ADCSRA, ADPS0) ;
#endif

//  Serial.println(sizeof(wave_I) / sizeof(wave_I[0]));

  pinMode(9, OUTPUT); //this is going to be where PWM signal comes out. Then goes to LPF.
  TCCR1B = (1 << CS10); //Timer runs at 16MHz
  TCCR1A |= (1 << COM1A1); //Sets pin low when TCNT1 = OCR1A
  TCCR1A |= (1 << WGM10); // This and next line sets 8-bit fast PWM mode
  TCCR1B |= (1 << WGM12);

  /*Get timer 2 ready to call interupt function*/
  TCCR2A = 0; //Control register A for timer 2
  TCCR2B = (1 << CS21); //Slow this one down so prescaler is divided by factor of 8
  TIMSK2 = (1 << OCIE2A); //When TCNT2=OCRA2 call the ISR

  //  OCR2A = 50; // Sets frequency  ???
  OCR2A = 450; // Sets frequency  34.7 Hz
  //  OCR2A = 511; // Sets frequency  27.67 Hz

  sei();//enable interupts
  establishContact();             //Wait for serial command from controller.
  digitalWrite(syncPin, LOW);
  digitalWrite(syncQPin, LOW);
}// end setup()

void loop() {

  /* After we have filled up the array signal from the ADC[], send array
    over to Processing via serial. Only the mixed I/Q data is sent
    filtering and display are to be done in processing.

    20220201
    Signal in at VCC/2 makes I and q = 0.
    signal in at VCC  makes I and q = +/- 313.
    signal in at GND  makes I and q = +/- 313.
    mixI and mixQ = 128
    2.5*128 = 320
    Mul by 0.0078125 to make volts.
    Mul by 7.8125 to make mV.
  */

  if ((index >= LENGTH - 1) & (Serial.available() > 0)) // We have a filled array and S port available.
  {
    int hold;
    for (int i = 0; i < LENGTH; i++)
    {
      //Serial.print(wave_I[i]);
      //Serial.print(',');
      hold = ((signal[i] - inputOFFSET) * 5.0 / 1023.0) * 7.8125 * (int(pgm_read_word_near(wave_I + i)) - 1 * TABLE_OFFSET) ;
      Serial.print(hold);//send in-phase mix
      Serial.print(',');
      hold = ((signal[i] - inputOFFSET) * 5.0 / 1023.0) * 7.8125 * (int(pgm_read_word_near(wave_Q + i)) - 1 * TABLE_OFFSET) ;
      Serial.println(hold);//send out-of-phase mix
    }// end FOR
  }
}// end looop()

ISR(TIMER2_COMPA_vect) { // Called when TCNT2 == OCR2A
  signal[index] = analogRead(myINPUT);
  OCR1AL = wave_I[index++]; // Update the PWM output
  //asm(“NOP;NOP”); // Fine tuning
  TCNT2 = 12; // Timing to compensate for ISR run time
  //Sync signal for oscilliscope. This will have zero phase delay (otherwise due to continious time LPF).
  if (index == 0) { 
    digitalWrite(syncPin, HIGH);
  }
  if (index ==   LENGTH /4) {
    digitalWrite(syncQPin, HIGH);
  }
  if (index ==   LENGTH / 2) {
    digitalWrite(syncPin, LOW);
  }
  if (index ==   LENGTH * 3/4) {
    digitalWrite(syncQPin, LOW);
  }
}//end ISR

//Wait for any character from controller to start data
void establishContact() {
  while (Serial.available() <= 0) {
    delay(300);
    Serial.println("2.5,0");   // send an initial string    
  }
}// end establishContact()

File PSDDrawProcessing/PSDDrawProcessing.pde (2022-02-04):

// {PSDDrawProcessing.}
//    Copyright (C) {2014}  Kevin D. Schultz
//
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
/*
 Modifyed by FLE 20220130
 Make ADC input for ADC2 for OctoUNO hardware.  Useing A2.
 Move graphing into draw()
 
 Got good ideas from:https://discourse.processing.org/t/how-to-solve-disabling-serialevent-for-com3-null/10214/4
 Fix error of type: Disabling serialEvent for COMn null”
 Move from serial event handler to main loop these lines
 mix = int(split(myString, ','));     // split the string at the commas // and convert the sections into integers:
 PSD(choice);        //Draw the PSD
 
 Change sin cos look up table for single range of 2 Pi
 20220201 Input from Arduino is now mV. So lets rescale the display
 */

import processing.serial.*;

String COMPANY = " ";
String MODELNAME = "PSD";
String VERSION = "2.0.0";  //Different enough from Kevin D. Schultz original to warrant V2.x.x.x

//float TC=200.0;
//float TC=100.0;
//float TC=50.0;
//float TC=5.0;
float TC=1.0;

//Exponetinal moveing average 
float x=exp(-1/TC);
float a=1-x;
float b=x;
float filter_out = 0;
float old_filter=0;// the value from the sensor

float I_filter_out;
float Q_filter_out;
float I_prev_filter;
float Q_prev_filter;

int linefeed = 10;      // linefeed in ASCII
Serial myPort;          // The serial port
int graphPosition = 0;  // the horizontal position of the latest
float prev_filter=0;                     // line to be drawn on the graph
int mix[];
float mix_I;
float mix_Q;

PFont f;
PFont myFont;

float phase;
int choice=0;

String myString ="";
boolean gotString = false;  //Flag for the serial event  
int totalNumber = 0;

int IQ_Zero = height/4;
int magnatudeZero = height/2;
int phaseZero = height*3/4;


void setup() {
  //  size(512, 256);
  size(1024, 800); //FLE
  surface.setTitle(COMPANY + ", " + MODELNAME + " Display, Version: " + VERSION);
  IQ_Zero = height/4;
  magnatudeZero = height/2;
  phaseZero = height*3/4;
  filter_out = magnatudeZero; //Start at zero line.

  background(0);
  stroke(0, 255, 100);    //Line color
  // List all the available serial ports
  printArray(Serial.list());
  f = createFont("Arial", 16, true);

  // I know that the first port in the serial list on my Mac
  // is always my  Arduino, so I open Serial.list()[4].
  // Open whatever port is the one you're using (the output
  // of Serial.list() can help; the are listed in order
  // starting with the one that corresponds to [4]).
  // read bytes into a buffer until you get a linefeed (ASCII 10):
  //myPort=new Serial(this, Serial.list()[6], 19200);
  //myPort=new Serial(this, Serial.list()[6], 38400);
  //  myPort=new Serial(this, Serial.list()[5],115200);        //FLE Make Faster
  myPort=new Serial(this, Serial.list()[6], 115200);        //FLE Make Faster
  //myPort=new Serial(this, Serial.list()[7],115200);        //FLE Make Faster
  myPort.bufferUntil('\n');
  delay(2000);          //Delay before sending character to start UNO aquiring data. Impericaly determined.
  myPort.write("A"); //Tell Arduino UNO to start aquizition.
}// end setup()

void draw() {
  if (gotString == true) {
    totalNumber++;
    mix = int(split(myString, ','));     // split the string at the commas // and convert the sections into integers:
    PSD(choice);        //Draw the PSD
  }

  //line(graphPosition-1, prev_filter, graphPosition, filter_out);
}



//Draw the PSD to the window.
void PSD(int option) {

  drawGraph();//Draw the axis

  x=exp(-1/TC); //ToDo identify, What are the units of TC???
  a=1-x;
  b=x;

  //Expected range of I and Q from Arduion in mV.
  float maxMIX = +2500;
  float minMIX = -2500;

  //Scale for about 1/4 of screen hight
  mix_I = map(mix[0], minMIX, maxMIX, -height/4, height/4);
  mix_Q = map(mix[1], minMIX, maxMIX, -height/4, height/4);
  print("N= " + totalNumber + ", mix[0]=" + mix[0]);  
  print(" mix[1]=" + mix[1]);
  print(", mixI=" + mix_I);  
  println(", mixQ=" + mix_Q);
  
  I_prev_filter = I_filter_out;
  Q_prev_filter = Q_filter_out;     
  I_filter_out = a * mix_I + b * I_prev_filter;
  Q_filter_out = a * mix_Q + b * Q_prev_filter;

  switch(option) {
  case 0: //Magnatude
    prev_filter = filter_out;
    //I_prev_filter = I_filter_out;
    //Q_prev_filter = Q_filter_out;     
    //I_filter_out = a*mix_I + b*I_prev_filter;
    //Q_filter_out = a*mix_Q + b*Q_prev_filter;
    filter_out= sqrt(I_filter_out * I_filter_out + Q_filter_out * Q_filter_out);  //Magnitude Offset to center FLE 20220201
    //filter_out=180+ atan(Q_filter_out/I_filter_out)*360/6.42; //Offset by 180 degrees FLE 20220201
    //    println("mag");
    fill(0);
    noStroke();
    rect(0, 0, width/2, 20);
    textFont(f, 16);                 // STEP 4 Specify font to be used
    stroke(255, 100, 0);    //Line color Magnatude
    line(graphPosition-1, (magnatudeZero-prev_filter), graphPosition, (magnatudeZero -filter_out));
    fill(156);                        // STEP 5 Specify font color 
    text("Magnitude="+(filter_out), 10, 20);
    break;

  case 1: //Inphase signal
    prev_filter=filter_out;
    filter_out = a*mix_I + b*prev_filter;
    //    println("in phase");
    fill(0);
    noStroke();
    rect(0, 0, width, 20);
    textFont(f, 16);                 // STEP 4 Specify font to be used
    fill(156);                         // STEP 5 Specify font color 
    text("I="+ filter_out, 10, 20);
    stroke(0, 100, 255);     //Line color Inphase
    line(graphPosition-1, (IQ_Zero - prev_filter), graphPosition, (IQ_Zero - filter_out));
    break;

  case 2: //Quadrature signal
    prev_filter=filter_out;
    filter_out= a*mix_Q + b*prev_filter;
    //    println("Quadature");
    fill(0);
    noStroke();
    rect(0, 0, width, 20);
    textFont(f, 16);                 // STEP 4 Specify font to be used
    fill(156);                         // STEP 5 Specify font color 
    text("Q="+ (filter_out-IQ_Zero), 10, 20);
    stroke(0, 255, 100);    //Line color Quadrature    
    line(graphPosition-1, (IQ_Zero - prev_filter), graphPosition, (IQ_Zero - filter_out));
    break;

  case 3: //Phase
    prev_filter=filter_out;
    //I_prev_filter = I_filter_out;
    //Q_prev_filter = Q_filter_out;     
    //I_filter_out = a * mix_I + b * I_prev_filter;
    //Q_filter_out = a * mix_Q + b * Q_prev_filter;
    filter_out = phaseZero + atan(Q_filter_out/I_filter_out)*360/6.42; //Offset by 180 degrees FLE 20220201
    //   println("phase= "+filter_out);
    fill(0);
    noStroke();
    rect(0, 0, width, 20);
    textFont(f, 16);                 // STEP 4 Specify font to be used
    fill(156);                         // STEP 5 Specify font color 
    text("phase="+ (filter_out- phaseZero), 10, 20);
    stroke(100, 255, 0);    //Line color Phase
    line(graphPosition-1, prev_filter, graphPosition, filter_out);
    break;
  }//end switch optins on keyboard input. 
  //  myPort.write("A"); //Tell Arduino UNO to start another aquizition.
  // println(filter_out);
}// end PSD()
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

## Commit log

2014-10-02 Update Talk Fix PSDDrawProcessing
    Talk updated
    Original PSDDrawProcessing had issues, fixed from local working copy.
    Added Screenshot capability while I was at it.
    [PSDDrawProcessing.pde]
2014-10-05 first attempt to fix phase
    [PSDDrawProcessing.pde]
2022-01-31 Add sync pin output to trigger Oscilliscope on oscillator output
    [PSDArduino.ino]
2022-01-31 Make ADC input for ADC2 for OctoUNO hardware. Useing A2. Fix serial event error.
    [PSDDrawProcessing.pde]
2022-02-01 Move sine and cosine table into PROGMEM. Scale the ADC, I, and Q signals to prevent clipping.
    [PSDArduino.ino]
2022-02-01 Rescale display with map function to fit with the output from arduino not that it is not clipping. Change time conast to fast so can see the modulated signals. Make space bar erase graph.
2022-02-02 Arduino Add a syncQ output on pin 7. Processing Add commands to manage TC. Resize window to display all four parameters with out overlap. Scale and offset the data recevied more appropratly. Add prog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
2022-02-02 Processing, add L and U keyboard commands. Move Snap.png to center mouse only.
    [UserInterface.pde]
2022-02-03 Add screen catpure showing all four traces on a free running input close to the local oscillator.
2022-02-03 Update README.md
    Add images from my work to show Processing graphing all four outputs. Arduino serial plotter of the I and Q output with A2 input of square wave from pin8 and pin 7 the I and Q phases of the local oscillator.

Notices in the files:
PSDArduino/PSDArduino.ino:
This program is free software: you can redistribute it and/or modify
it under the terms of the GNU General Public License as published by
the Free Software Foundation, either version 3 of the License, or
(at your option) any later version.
